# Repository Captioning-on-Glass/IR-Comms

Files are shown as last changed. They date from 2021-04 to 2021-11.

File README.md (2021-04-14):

# InfraRed Communications for Captioning on Glass

This repository holds the Arduino code required to simulate real-time captioning using smart glasses.
## List of Materials
You will need:
- An Android device (a Google Pixel running LineageOS was used for experimentation)
- A USB OTG connector to connect your Android device to an Arduino
- 6 Arduino boards of any kind (recommended: 5 [Arduino Nano](https://store.arduino.cc/usa/arduino-nano)s + 1 [Seeeduino ADK Main Board](https://www.seeedstudio.com/Seeeduino-ADK-Main-Board-p-846.html))
- 4 IR Receiver Diodes (went with [TSOP38238](https://www.sparkfun.com/products/10266))
- 1 IR LED (went with [a 950mm from SparkFun](https://www.sparkfun.com/products/9349))
- Wires and resistors as necessary to keep your hardware from shorting.

The hardware should be set up to look something like this:
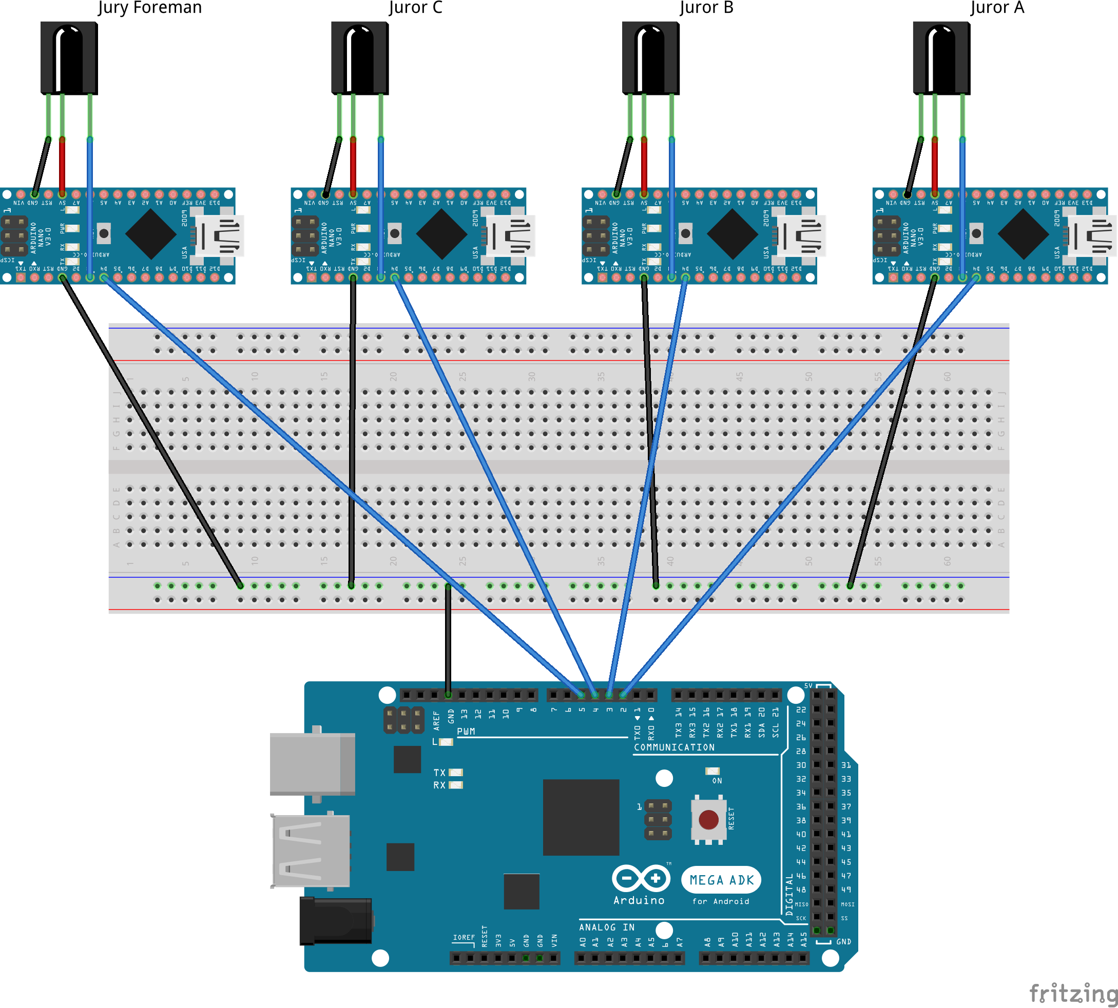
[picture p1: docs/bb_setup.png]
Fritzing Circuit Diagram


## Design
This system works using a primary/secondary approach.
One board mounted to the smartglasses outputs a constant IR signal, focused in the user's head orientation.
Secondary boards connected to IR receiver diodes receive the IR signal from the glasses, and output signals to a primary board connected to the Android device.
(The primary/secondary board approach was implemented to circumvent some limitations in the [Arduino-IRremote library involving multiple IR receivers](https://github.com/Arduino-IRremote/Arduino-IRremote/discussions/843)).
The primary board reads the secondary boards' outputs, and writes to the serial port so the Android can read it.
The Android device reads from the serial port (see [the Android app repository for more information](https://github.com/SaltyQuetzals/CaptioningOnGlass-Notify/)), and then sends messages to the smartglasses via Bluetooth.
The smartglasses then display the transmitted messages on the user's field of vision, simulating a real-time captioning experience.

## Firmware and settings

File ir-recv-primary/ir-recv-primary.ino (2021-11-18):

#include "JurorBuffer.hpp"

#define JUROR_A_SECONDARY_PIN 2
#define JUROR_B_SECONDARY_PIN 3
#define JUROR_C_SECONDARY_PIN 4
#define JURY_FOREMAN_SECONDARY_PIN 6

JurorBuffer buffer;
void setup()
{
    pinMode(JUROR_A_SECONDARY_PIN, INPUT);
    pinMode(JUROR_B_SECONDARY_PIN, INPUT);
    pinMode(JUROR_C_SECONDARY_PIN, INPUT);
    pinMode(JURY_FOREMAN_SECONDARY_PIN, INPUT);
    Serial.begin(9600);
    buffer = JurorBuffer();
}

void loop()
{
    auto jurorAResult = digitalRead(JUROR_A_SECONDARY_PIN);
    auto jurorBResult = digitalRead(JUROR_B_SECONDARY_PIN);
    auto jurorCResult = digitalRead(JUROR_C_SECONDARY_PIN);
    auto juryForemanResult = digitalRead(JURY_FOREMAN_SECONDARY_PIN);
    if (jurorAResult || jurorBResult || jurorCResult || juryForemanResult)
    {
        if (jurorAResult == HIGH)
        {
            buffer.add(JUROR_A_VALUE);
            // Serial.println(JUROR_A_VALUE);
        }
        if (jurorBResult == HIGH)
        {
            buffer.add(JUROR_B_VALUE);
            // Serial.println(JUROR_B_VALUE);
        }

        if (jurorCResult == HIGH)
        {
            buffer.add(JUROR_C_VALUE);
            // Serial.println(JUROR_C_VALUE);
        }

        if (juryForemanResult == HIGH)
        {
            buffer.add(JURY_FOREMAN_VALUE);
            // Serial.println(JURY_FOREMAN_VALUE);
        }
    }
    else
    {
        buffer.add(NO_SIGNAL);
        // Serial.println("X");
    }
    if (buffer.is_full()) {
        // printBuffer(buffer);
        Serial.println(buffer.mode());
        buffer.clear();
        Serial.flush();
    }
    delay(10);
}

void printBuffer(JurorBuffer buffer) {
    Serial.print("[");
    for (auto i = 0; i < buffer.BUFFER_SIZE; ++i) {
        Serial.print(buffer.buf[i]);
        if (i < buffer.BUFFER_SIZE - 1) {
        Serial.print(", ");
        }
    }
    Serial.println("]");
}

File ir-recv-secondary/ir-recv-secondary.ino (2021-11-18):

/**
 * Modified example of examples/SimpleReceiver.cpp from https://github.com/Arduino-IRremote/Arduino-IRremote
 * Rather than just outputting to the serial monitor, 
 * this secondary board will output a signal to the primary 
 * board to indicate that it got something. 
 */
#include <IRremote.h>
#define IR_RECEIVE_PIN A0
#define IR_COMMAND 0x40
#define OUTPUT_PIN A1

void setup()
{
    Serial.begin(115200);
    // Just to know which program is running on my Arduino
    Serial.println(F("START " __FILE__ " from " __DATE__ "\r\nUsing library version " VERSION_IRREMOTE));

    /*
     * Start the receiver, enable feedback LED and take LED feedback pin from the internal boards definition
     */
    IrReceiver.begin(IR_RECEIVE_PIN, ENABLE_LED_FEEDBACK, USE_DEFAULT_FEEDBACK_LED_PIN);
    pinMode(OUTPUT_PIN, OUTPUT);
    Serial.print(F("Ready to receive IR signals at pin "));
    Serial.println(IR_RECEIVE_PIN);
}

void loop()
{
    /*
     * Check if received data is available and if yes, try to decode it.
     * Decoded result is in the IrReceiver.decodedIRData structure.
     *  
     * E.g. command is in IrReceiver.decodedIRData.command
     * address is in command is in IrReceiver.decodedIRData.address
     * and up to 32 bit raw data in IrReceiver.decodedIRData.decodedRawData
     */
    if (IrReceiver.decode())
    {
        
        // Print a short summary of received data
        IrReceiver.printIRResultShort(&Serial);
        if (IrReceiver.decodedIRData.protocol == UNKNOWN)
        {
            Serial.print("Command = ");
            Serial.println(IrReceiver.decodedIRData.command);
            // We have an unknown protocol here, print more info
            IrReceiver.printIRResultRawFormatted(&Serial, true);
        }
        Serial.println();

        /*
         * !!!Important!!! Enable receiving of the next value,
         * since receiving has stopped after the end of the current received data packet.
         */
        IrReceiver.resume(); // Enable receiving of the next value
        // if (IrReceiver.decodedIRData.command == IR_COMMAND)
        // {
            digitalWrite(OUTPUT_PIN, HIGH);
            delay(150);
        // }
    }
    else
    {
        digitalWrite(OUTPUT_PIN, LOW);
    }
}

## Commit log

2021-04-14 Added some basic documentation.
    [CoG Arduino Setup.fzz]
2021-04-27 New version, system working, trying to reduce noise from misread signals.
    [ir-recv-primary.ino, ir-recv-secondary.ino, ir-transmit.ino]
2021-11-18 Updated pins for soldered results
